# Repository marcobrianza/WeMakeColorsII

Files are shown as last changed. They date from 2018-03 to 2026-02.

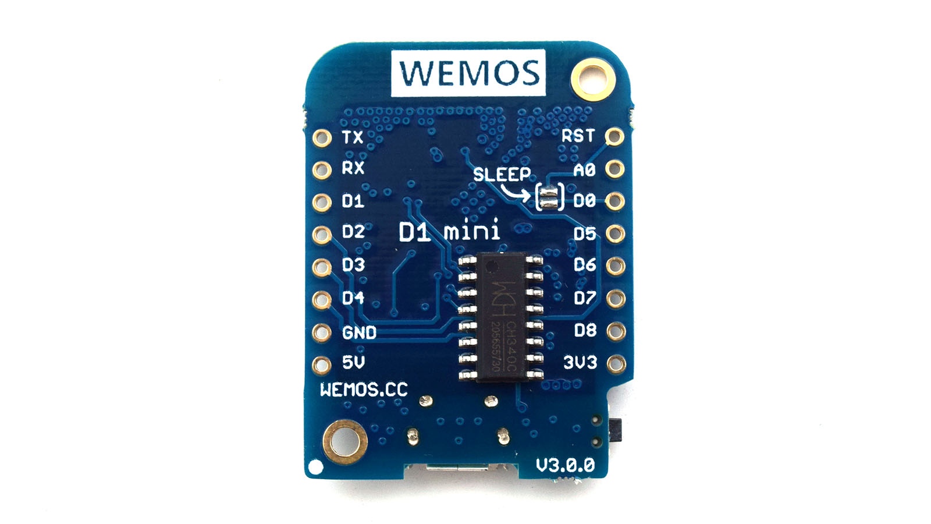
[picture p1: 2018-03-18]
hardware/d1_mini_v3.0.0_2_16x9.jpg

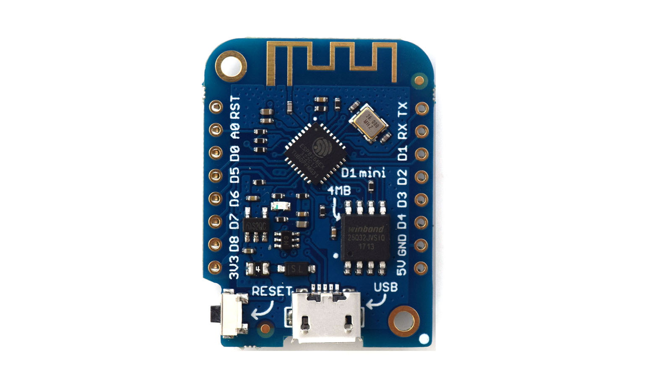
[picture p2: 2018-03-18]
hardware/d1_mini_v3.0.0_1_16x9.jpg

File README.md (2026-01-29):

# WeMakeColors II

An open minimal light-based interaction device connecting distant spaces through ambient presence

## What it is

We Make Colors is an open and networked light project that connects multiple physical spaces through a minimal visual signal. Each installation consists of only two RGB pixels and a light sensor. Despite its extreme simplicity, the project makes the presence of other spaces perceptible through light variation.

The project is open source and designed to be replicated, modified, and expanded by others.
Concept
We Make Colors explores how spaces, rather than people, can be in relation through a network. The interaction is anonymous and non-verbal: no messages, no identities, no content is exchanged. Only light changes.

A variation in ambient light in one space generates a color. That color appears locally and is simultaneously transmitted to all connected spaces. Seeing a color change is enough to understand that something happened somewhere else.

This creates a minimal form of social interaction based on presence rather than communication.
Across Spaces – Key Questions
Which spaces are connected?
Independent physical spaces (rooms, studios, homes, classrooms) connected via the internet.

## What travels through the network?

Only color values generated by light variations. No personal data, no identity, no message.

## How does light make this visible?
Light acts as a direct visual signal. A changing pixel makes remote activity perceptible without explanation.

## Is the interaction intentional or ambient?

Primarily ambient. Light variations can be caused intentionally (touching, covering the sensor) or unintentionally (day/night cycle, movement, shadows).
How it works (simplified)
- A photoresistor detects changes in ambient light
- When a significant variation occurs, a random color is generated
- The color appears on the local pixel
- The same color is sent via MQTT to all connected devices
- Each device always shows two pixels:
  • one representing the local space
  • one representing all other connected spaces

This creates a constant visual relationship between 'here' and 'elsewhere'.
Light as Minimal Display
The project uses the smallest possible digital display: two pixels. The pixel is the minimal unit of digital visual information. With only two pixels, the project reduces digital art to its essential condition: relation.

A single pixel has no strong meaning by itself. Two pixels allow comparison, contrast, and interaction.
Openness
Hardware: open and reproducible using digital fabrication.
Software: open source Arduino 
Concept: adaptable and extendable  (GitHub) https://github.com/marcobrianza/WeMakeColorsII

We Make Colors is not a closed artwork but a framework for further projects. Students’ works inspired by it continue the same logic while developing new forms and functions.
Why this matters
The project shows that connection does not require complexity. Minimal signals can create meaningful relationships between spaces. The work suggests an alternative to social platforms based on visibility, identity, and control, proposing instead an ambient and anonymous form of coexistence.

[http://www.marcobrianza.it/wemakecolors-ii/
](http://www.marcobrianza.it/wemakecolors-ii/)

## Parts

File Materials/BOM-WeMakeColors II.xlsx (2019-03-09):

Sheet: bom 1.1
WeMakeColorsII Bill of materials | 2018-01-10
https://www.tme.eu/it/Profile/Parking/1219222.html
 | Product code | Details | Pieces lot | Price lot | Price Piece | Parts | Price parts € | Origin | Shipping cost | Price category | Link
Plexiglass white 3mm | WN297 GT | 1100x1040 | 42 | 39.60 | 0.943 | 1 | 0.94 | DE | 15 |  | https://www.plexiglas-shop.com/Products/Sheet/PLWN297GT-3-00-3050X2050-03-01-X.html (https://www.plexiglas-shop.com/IT/it/xt-allround-8ny276huqre/plexiglas-xt-allround-bianco-wn297-gt-cfy07wjb25z~p.html)
PLEXIGLAS® Film, white - 1,0 mm | 99532 GT | 420x297 | 40 | 8.09 | 0.202 | 1 | 0.20 | DE |  |  | https://www.plexiglas-shop.com/Products/FF99532-1-000.html
PLEXIGLAS® Film Clear - 0,5 mm | 99524 GT | 420x297 | 80 | 5.39 | 0.067 | 1 | 0.07 | DE |  | 1.21 | https://www.plexiglas-shop.com/Products/FF99524GT-0-5-420x297.html?listtype=search&searchparam=99524
LED strip 2 LEDs | White 1m 30 IP20 | WS2812 | 30 | 11.04 | 0.368 | 2 | 0.74 | PL | 0 |  | https://www.tme.eu/it/details/hcaaa30w/fonti-di-luce-led-a-nastro/worldsemi/hc-f5v-30l-30led-wip20/
ESP8266 | Wemos D1 mini | 3.1 |  |  | 3.140 | 1 | 3.14 | CN | 0.4 |  | https://it.aliexpress.com/item/D1-mini-Mini-NodeMcu-4M-bytes-Lua-WIFI-Internet-of-Things-development-board-based-ESP8266/32529101036.html
LIGHT Sensor | PGM5659D | 150-300k Ohm |  |  |  | 1 | 0.17 | PL | 0 |  | https://www.tme.eu/it/details/pgm5659d/fotoresistori/token/
connecting wire | BQ CABLE SCW-0.60/100 |  | 40 | 13.02 | 0.326 | 0.3 | 0.10 | PL | 0 |  | https://www.tme.eu/it/details/scw-0.60_100/filo-di-rame-argentato/bq-cable/
USB Cable | White 3m |  |  |  |  | 1 | 1.67 | PL | 0 |  | https://www.tme.eu/it/details/usb-micbm-3.0/cavi-e-adattatori-usb/goobay/96194/
USB Power supply 1A | a1400 type |  |  |  |  | 1 | 2.85 | PL | 0 | 8.67 | https://www.tme.eu/it/details/ak-ch-03w/alimentatori-a-spina/akyga/ccabkeyaky-07309/
screw 2x30 | B2X30/BN330 |  |  |  | 0.037 | 4 | 0.15 | PL | 7.9 |  | http://www.tme.eu/it/details/b2x25_bn330/bulloni/bossard/1122886/
screw 2x8 | B2X8/BN650 |  |  |  | 0.020 | 2 | 0.04 | PL |  |  | http://www.tme.eu/it/details/b2x10_bn341/bulloni/bossard/1127799/
bolt 2ma | B2/BN628 |  |  |  | 0.013 | 8 | 0.10 | PL |  | 0.29 | http://www.tme.eu/it/details/b2_bn628/dadi/bossard/m2bn628/
 |  |  |  |  |  | TOTAL € | 10.17 |  |  | 10.17

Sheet: alternatives
WeMake Colors Bill of materials
 | Product code | Details | Pieces lot | Price lot | Price Piece | Parts | Price parts | Origin | Shipping cost | Price cathegory | Link
USB Power supply 1A | AK-CH-03W |  |  |  | 2.2800 | 1 | 2.28 | PL | 7.9 | 2.28 | http://www.tme.eu/it/details/ak-ch-03w/alimentatori-a-presa-di-corrente/akyga/ccabkeyaky-07309/
USB Cable | White 3M flat |  | 10 | 10.47 | 1.0470 | 1 | 1.05 | CN | 0 |  | http://it.aliexpress.com/item/Fedex-shipping-100pcs-lot-3M-Noodle-flat-color-USB-Micro-cable-for-HTC-Samsung-Galaxy-S3/1472726264.html
spacer 2x15 | FIX-TP2-15 | plastic discontinued

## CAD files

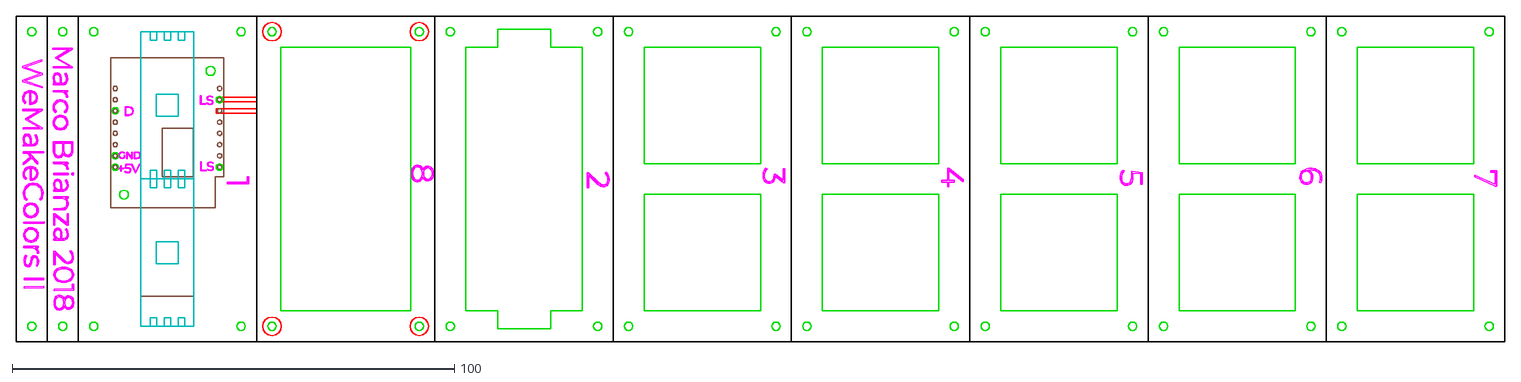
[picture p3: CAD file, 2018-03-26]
design/production/WeMakeColors II 1.0.dxf
336.6 x 73.7

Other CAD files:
design/WeMakeColorsII_1.0.3dm

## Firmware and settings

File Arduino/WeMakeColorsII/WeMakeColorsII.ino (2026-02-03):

// tested on ESP8266 Core 3.1.2
// Flash Size: "4MB (FS:2MB OTA:~1019KB)
// lwIP Variant: "v2 Lower Memory"
// https://arduino.esp8266.com/stable/package_esp8266com_index.json


#define WMCII 0
#define IOTKIT 1

#define BOARD_TYPE WMCII  // please define one of the above boards

boolean DEBUG_MAIN = true;

#include "info.h"
#include "miniUI.h"
#include "app_status.h"
#include "WiFi.h"
#include "time.h"
#include "app.h"
#include "MQTT.h"
#include "WiFiManager.h"


void setup() {
  miniUI_Setup();
  softwareInfo_setup("");
  app_setup();


  loadParametersFromFile();

  uint8_t bc = miniUI_bootCount();
  if (bc == BOOT_TEST_DEVICE)  app_testDevice();

  ledON();
  WiFi_setup();

  // test parameters
  //connectWiFi("PucciCube24", "Grandebellezza3!");
  //mqttServer = "192.168.1.5";

  switch  (bc) {
    case BOOT_RESET:
      if (DEBUG_MAIN) Serial.println("Reset parameters");
      saveParametersToFile();
      connectWiFi_Manager(true);
      break;

    case BOOT_DEFAULT_AP:
      if (DEBUG_MAIN) Serial.println("Reset parameters and connecting to default AP");
      saveParametersToFile();
      connectWiFi("", "");
      break;

    case BOOT_ESPTOUCH:
      connectWiFi_Smart();
      break;
    default:
      connectWiFi_Manager(false);
  }

  autoUpdate();
  OTA_setup();
  WebUpdate_setup() ;
  mqtt_setup();
  Setup_Time();

  ledOFF();
  if (DEBUG_MAIN) Serial.println("BOARD_TYPE:" + String(BOARD_TYPE));
  if (DEBUG_MAIN) Serial.println("starting loop");


}

void loop() {

  miniUI_loop();
  WiFi_loop();
  mqtt_loop();

  // app loop----------------

  if ((millis() - lastAppTime) > APP_INTERVAL)  {
    lastAppTime = millis();
    if (checkLight()) {
      hsvColor_t c = newRndColor();
      setLED(MY_LED, c);
      publishEvent(c);
    }
  }



#if BOARD_TYPE==IOTKIT
  if ( ((millis() - lastButtonTime) > BUTTON_INTERVAL) && !digitalRead(BUTTON) )  {
    lastButtonTime = millis();

    hsvColor c = newRndColor();
    setLED(MY_LED, c);
    publishEvent(c);
  }
#endif

  if (newSettings) {
    newSettings = false;
    saveParametersToFile();
  }
  delay(1);
}

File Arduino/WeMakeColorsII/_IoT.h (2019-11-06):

#include <EEPROM.h> //boot Count

//Wi-Fi
#include <ESP8266WiFi.h>  // ESP8266 core 2.5.2
WiFiClient wifiClient;

//default ssid password
String defaultSSID = "colors";
String defaultPassword = "colors01";

//Wi-FiManager
#include "FS.h"
#include <DNSServer.h>
#include <ESP8266WebServer.h>
#include <WiFiManager.h> // 0.14 
#define COUNT_ADDR 0

String thingId = "";
String appId = "WMCII";
String friendlyName = "";

#define MAX_PARAM 40

// name, prompt, default, length
WiFiManagerParameter wfm_friendlyName("friendlyName", "Friendly Name", friendlyName.c_str(), MAX_PARAM);
WiFiManagerParameter wfm_mqttServer("mqttServer", "MQTT Server", mqttServer.c_str(), MAX_PARAM);
WiFiManagerParameter wfm_mqttUsername("mqttUsername", "MQTT Username", mqttUsername.c_str(), MAX_PARAM);
WiFiManagerParameter wfm_mqttPassword("mqttPassword", "MQTT Password", mqttPassword.c_str(), MAX_PARAM);


#define CAPTIVE_TIMEOUT 300
#define CAPTIVE_SIGNAL_QUALITY 10

#define BLINK_NO_SSID 1
#define BLINK_CONNECTION_ERROR 2

unsigned int upTime = 0;
//status
#define STATUS_INTERVAL 5 //minutes
boolean publishStatus = false;

//OTA
#include <ESP8266mDNS.h>
#include <ArduinoOTA.h>
String OTA_PASSWORD = "12345678";

//http update
#include <ESP8266HTTPClient.h>
#include <ESP8266httpUpdate.h>

String MD5_URL = "http://iot.marcobrianza.it/art/WeMakeColorsII.md5.txt";
String FW_URL = "http://iot.marcobrianza.it/art/WeMakeColorsII.ino.d1_mini.bin";


void setup_IoT(){
 thingId = appId + "_" +  WiFi.macAddress().c_str();
}


void upTimeInc() {
  upTime++;
  //publishStatus = true;
  if (upTime % STATUS_INTERVAL == 0 )publishStatus = true;
}


//---- file attribute functions----

String readAttribute(String attributeName) {
  String value = "";
  if (SPIFFS.begin()) {
    File configFile = SPIFFS.open(attributeName + ".txt", "r");
    if (configFile) {
      value = configFile.readString();
      Serial.println("readAttribute: " + attributeName + "=" + value);
    } else {
      Serial.println("readAttribute: " + attributeName + "= null" );
    }
    configFile.close();
    SPIFFS.end();
  } else Serial.println("readAttribute ERROR: cannot open file system");
  return value;
}

String deleteAttribute(String attributeName) {
  if (SPIFFS.begin()) {
    String value = "";
    SPIFFS.remove(attributeName + ".txt");
  } else Serial.println("deleteAttribute ERROR: cannot open file system");
}

void writeAttribute(String attributeName, String value) {
  if (SPIFFS.begin()) {
    File configFile = SPIFFS.open(attributeName + ".txt", "w");
    if (configFile) {
      configFile.print(value);
      Serial.println("writeAttribute: " + attributeName + "=" + value);
    } else  Serial.println("writeAttribute: ERROR cannot open file " + attributeName);
    configFile.close();
    SPIFFS.end();
  } else Serial.println("writeAttribute ERROR: cannot open file system");
}


void loadParametersFromFile() {
  String temp = "";

  // convert the old attribute
  temp = readAttribute("thingName");
  if (temp != "") {
    Serial.println ("thingName=" + friendlyName);
    writeAttribute("friendlyName", temp);
    deleteAttribute("thingName");
  }


  temp = readAttribute("friendlyName");
  if (temp != "") friendlyName = temp;
  Serial.println ("friendlyName=" + friendlyName);

  temp = readAttribute("mqttServer");
  if (temp != "")  mqttServer = temp;
  Serial.println ("mqttServer=" + mqttServer);

  temp = readAttribute("mqttUsername");
  if (temp != "") {
    mqttUsername = temp;
  } else {
    mqttUsername = thingId; // if username is null it defaults to thingId
  }
  Serial.println ("mqttUsername=" + mqttUsername);

  temp = readAttribute("mqttPassword");
  if (temp != "")  mqttPassword = temp;
  Serial.println ("mqttPassword=" + mqttPassword);

}




void saveParametersToFile() {
  writeAttribute("mqttServer", mqttServer);
  writeAttribute("mqttUsername", mqttUsername);
  writeAttribute("mqttPassword", mqttPassword);
  writeAttribute("friendlyName", friendlyName);
}

// -------------------------------------------
byte bootCount() {

  pinMode(LED_BUILTIN, OUTPUT);
  digitalWrite(LED_BUILTIN, LED_OFF);
  delay(500);

  EEPROM.begin(512);
  byte boot_count = EEPROM.read(COUNT_ADDR);
  boot_count++;
  for (int i = 0;  i  < boot_count; i++) {
    digitalWrite(LED_BUILTIN, LED_ON);
    delay(300);
    digitalWrite(LED_BUILTIN, LED_OFF);
    delay(300);
  }

  EEPROM.write(COUNT_ADDR, boot_count);
  EEPROM.commit();

  delay(2000);

  EEPROM.write(COUNT_ADDR, 0);
  EEPROM.commit();
  return boot_count;
}


int checkWiFiStatus() {

  String s = "";
  int c = WiFi.status();
  int b = 0;

  switch (c) {
    case WL_CONNECTED:
      s = "WL_CONNECTED";
      break;
    case WL_NO_SSID_AVAIL:
      s = "WL_NO_SSID_AVAIL";
      b = BLINK_NO_SSID;
      break;
    case WL_CONNECT_FAILED:
      s = "WL_CONNECT_FAILED";
      b = BLINK_CONNECTION_ERROR;
      break;
    case WL_IDLE_STATUS:
      s = "WL_IDLE_STATUS";
      break;
    case WL_DISCONNECTED:
      s = "WL_DISCONNECTED";
      break;
    case WL_CONNECTION_LOST:
      s = "WL_CONNECTION_LOST";
      break;
    default:
      s = "UNKNOWN";
      break;
  }

  Serial.println( "WiFi Status=" + String(c) + " " + s);
  if (b > 0) blink(b);
  return c;
}



// ------ Wi-Fi Manager functions-------------------------------------


void connectWifi(String ssid, String password) {
  WiFi.disconnect();
  delay(100);
  // We start by connecting to a WiFi network
  Serial.print("Connecting to: "); Serial.println(ssid);

  WiFi.begin(ssid.c_str(), password.c_str());

  while (WiFi.status() != WL_CONNECTED) {
    delay(500);
    Serial.print(".");
  }

  IPAddress ip = WiFi.localIP();
  Serial.println("WiFi connected");
  Serial.print("IP address: ");
  Serial.println(ip);
  WiFi.setAutoReconnect(true);
}



void configModeCallback (WiFiManager *myWiFiManager) {
  Serial.println("Entered config mode");
  Serial.println(WiFi.softAPIP());
  Serial.println(myWiFiManager->getConfigPortalSSID());
  showAllLeds(0, 0, 255);
}


void saveConfigCallback () {
  Serial.println("Config callback");
  if (String(wfm_friendlyName.getValue()) != "") friendlyName = wfm_friendlyName.getValue();
  if (String(wfm_mqttServer.getValue()) != "")  mqttServer = wfm_mqttServer.getValue();
  if (String(wfm_mqttUsername.getValue()) != "") mqttUsername = wfm_mqttUsername.getValue();
  if (String(wfm_mqttPassword.getValue()) != "") mqttPassword = wfm_mqttPassword.getValue();

  saveParametersToFile();
  showAllLeds(0, 255, 255);
}
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

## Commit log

2018-03-18 first release, workshop in Frankfurt @luminale 2018
    [BOM-WeMakeColors II.xlsx, WeMakeColorsII_1.0.3dm]
2018-03-26 readme with IDE links and minor stuff
    [WeMakeColors II 1.0.dxf]
2018-06-24 attemp to fix reconnect some structure refactoring to have a more generic program structure
    [IoT.ino, WeMakeColorsII.ino, light.ino]
2018-08-04 switching to ESP8266 core 2.4.2. updated WiFiManager and arduinoJson
2018-11-09 Version 1.2.2 tested with updated libraries and Arduino IDE 1.8.7
2018-11-11 Version 1.2.3 updated IDE links, reset all settings in DEFAULT_AP mode
    [WeMakeColorsII.ino]
2019-03-09 1.3.2 minor refactoring
    [BOM-WeMakeColors II.xlsx]
2019-03-12 1.4.5 various improvements on the way to a better IoT framework
2019-03-12 1.5.1 blinks for connection errors
    [IoT.ino, WeMakeColorsII.ino]
2019-08-04 1.7.2 fix missing code
    [WeMakeColorsII.ino, _IoT.h]
2019-11-06 1.7.9 fixed mqtt.loop() issue
    [WeMakeColorsII.ino, _IoT.h]
2019-11-06 1.8.1 ArduinoJson 6 etc
2019-12-08 1.9.16 fix config messages parsing
    [WeMakeColorsII.ino]
2020-01-20 1.10.0 review miniUI e LED management
2020-01-26 1.11.0 fixed autoreconnect and introduced :softwareInfo file
    [WeMakeColorsII.ino]
2020-01-26 1.11.1 real fix for wifi reconnect?
    [WeMakeColorsII.ino]
2020-01-31 most debug messages filtered
2020-02-08 1.16.1 fixed app trigger, introduced showStatus
    [WeMakeColorsII.ino]
2020-02-10 1.18.1 fixed retained in status message
    [WeMakeColorsII.ino]
2020-02-12 1.19.0 new concept: status, event, sensor
2021-02-01 1.31.2 tested with updated libraries + defines for LED
2021-02-01 1.40.1 support for BOARD_TYPE and button handling for IOTKIT
2021-07-12 1.5.0 working on compatibility for esp core 3.0.1 (still fastled issue)
    [WeMakeColorsII.ino]
2022-02-16 trying to fix 3.x core not working
    [WeMakeColorsII.ino]
2023-03-19 1.90.1 name changing to support arduino ide 2.0.4
2023-03-19 1.92.0 added time and some missing old files
    [LED.h, WeMakeColorsII.ino, app.h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]
2026-02-03 1.95.0 updating lib compatibility and using uint8_t instead of byte type + fixes
    [LED.h, WeMakeColorsII.ino, app.h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]
